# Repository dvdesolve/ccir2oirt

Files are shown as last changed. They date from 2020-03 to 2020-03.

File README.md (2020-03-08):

# ccir2oirt
This converter is intended for shifting radio frequency down so old radio receivers which works in OIRT range (mostly produced in Soviet Union) become able to receive modern CCIR range. It have 3 frequency range selectors: 88-96, 95-103 and 101-109 MHz. Input voltage is quite wide and spans from 7V to 25V (for both positive and negative versions). It's recommended to place the whole device in solid aluminum box to prevent unintended RF interference.

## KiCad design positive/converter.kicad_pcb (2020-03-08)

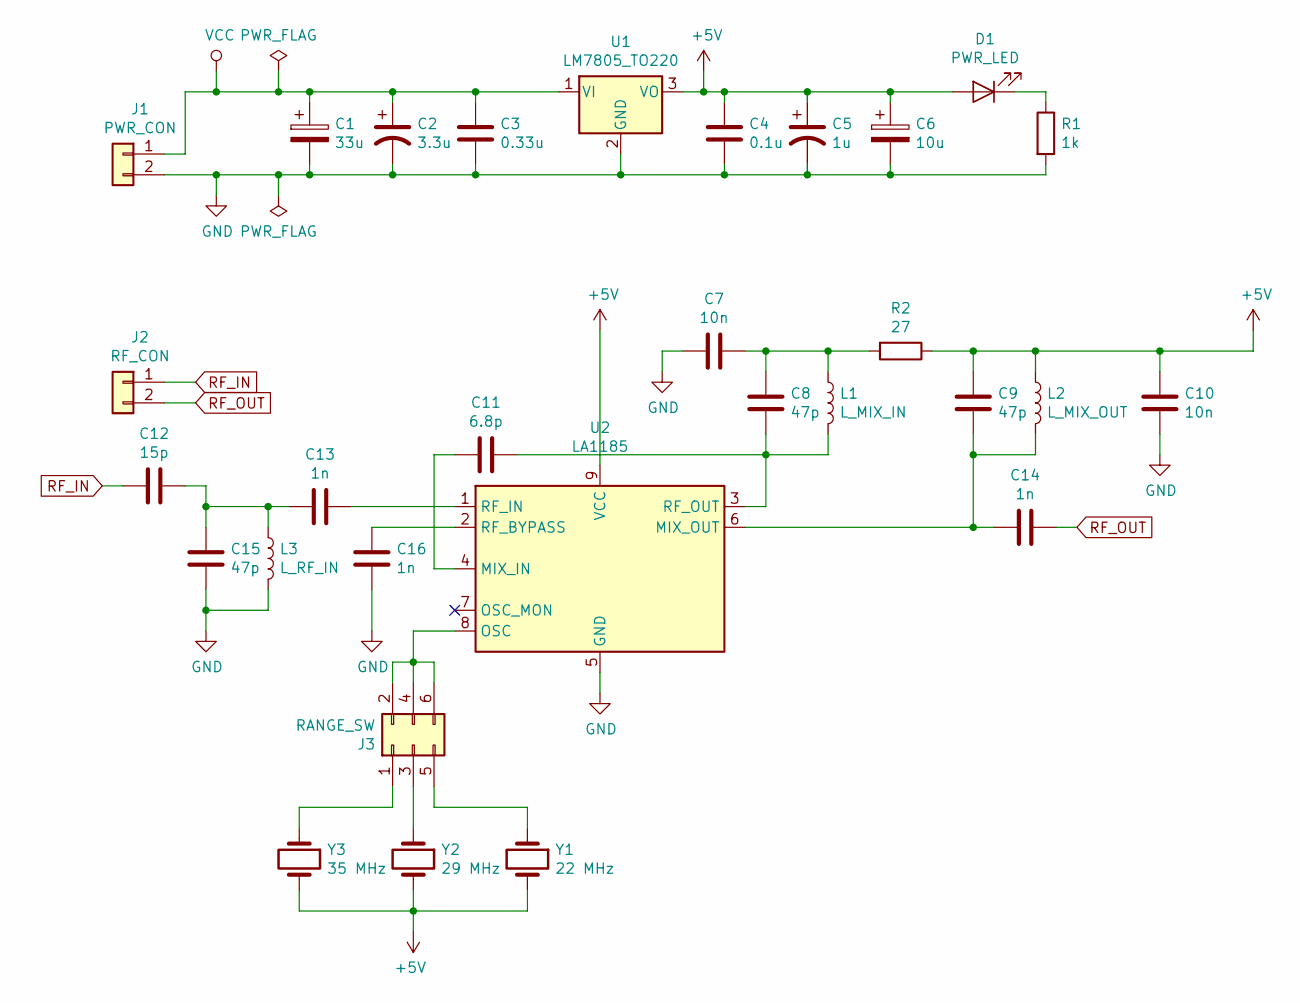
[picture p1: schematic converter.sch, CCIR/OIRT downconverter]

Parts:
C1: 33u; CP_Radial_D5.0mm_P2.00mm
C2: 3.3u; CP_EIA-3528-21_Kemet-B_Pad1.50x2.35mm_HandSolder
C3: 0.33u; C_Disc_D4.7mm_W2.5mm_P5.00mm
C4: 0.1u; C_Disc_D4.7mm_W2.5mm_P5.00mm
C5: 1u; CP_EIA-3216-18_Kemet-A_Pad1.58x1.35mm_HandSolder
C6: 10u; CP_Radial_D5.0mm_P2.00mm
C7, C10: 10n; C_Disc_D4.7mm_W2.5mm_P5.00mm
C8, C9, C15: 47p; C_Disc_D4.7mm_W2.5mm_P5.00mm
C11: 6.8p; C_Rect_L6.8mm_W4.6mm_P2.50mm
C12: 15p; C_Disc_D4.7mm_W2.5mm_P5.00mm
C13, C14, C16: 1n; C_Disc_D4.7mm_W2.5mm_P5.00mm
D1: PWR_LED; LED_D5.0mm
J1: PWR_CON; Connfly_DS1070-2MR_1x02_P2.54mm
J2: RF_CON; Connfly_DS1070-2MR_1x02_P2.54mm
J3: RANGE_SW; PinHeader_2x03_P2.54mm_Horizontal
L1: L_MIX_IN; L_Axial_4Turns_d0.8mm_D4.5mm_WP1.0mm
L2: L_MIX_OUT; L_Axial_6Turns_d0.8mm_D4.5mm_WP1.0mm
L3: L_RF_IN; L_Axial_4Turns_d0.8mm_D4.5mm_WP1.0mm
R1: 1k; R_Axial_DIN0207_L6.3mm_D2.5mm_P10.16mm_Horizontal
R2: 27; R_Axial_DIN0207_L6.3mm_D2.5mm_P10.16mm_Horizontal
U1: LM7805_TO220; TO-220-3_Vertical
U2: LA1185; SIP-9_21.54x3mm_P2.54mm
Y1: 22 MHz; Crystal_HC49-U_Vertical
Y2: 29 MHz; Crystal_HC49-U_Vertical
Y3: 35 MHz; Crystal_HC49-U_Vertical

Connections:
+5V: C4.1, C5.1, C6.1, C9.1, C10.1, D1.2 (A), L2.1, R2.1, U1.3 (VO), U2.9 (VCC), Y1.2, Y2.2, Y3.2
GND: C1.2, C2.2, C3.2, C4.2, C5.2, C6.2, C7.2, C10.2, C15.2, C16.2, J1.2, L3.2, R1.2, U1.2 (GND), U2.5 (GND); also elsewhere on the board
unnamed: C7.1, C8.1, L1.1, R2.2
unnamed: C8.2, C11.1, L1.2, U2.3 (RF_OUT)
unnamed: C11.2, U2.4 (MIX_IN)
unnamed: C12.1, C13.2, C15.1, L3.1
unnamed: C13.1, U2.1 (RF_IN)
unnamed: C9.2, C14.2, L2.2, U2.6 (MIX_OUT)
unnamed: C16.1, U2.2 (RF_BYPASS)
unnamed: D1.1 (K), R1.1
unnamed: J3.1, Y3.1
unnamed: J3.2, J3.4, J3.6, U2.8 (OSC)
unnamed: J3.3, Y2.1
unnamed: J3.5, Y1.1
RF_IN: C12.2, J2.1
RF_OUT: C14.1, J2.2
VCC: C1.1, C2.1, C3.1, J1.1, U1.1 (VI)

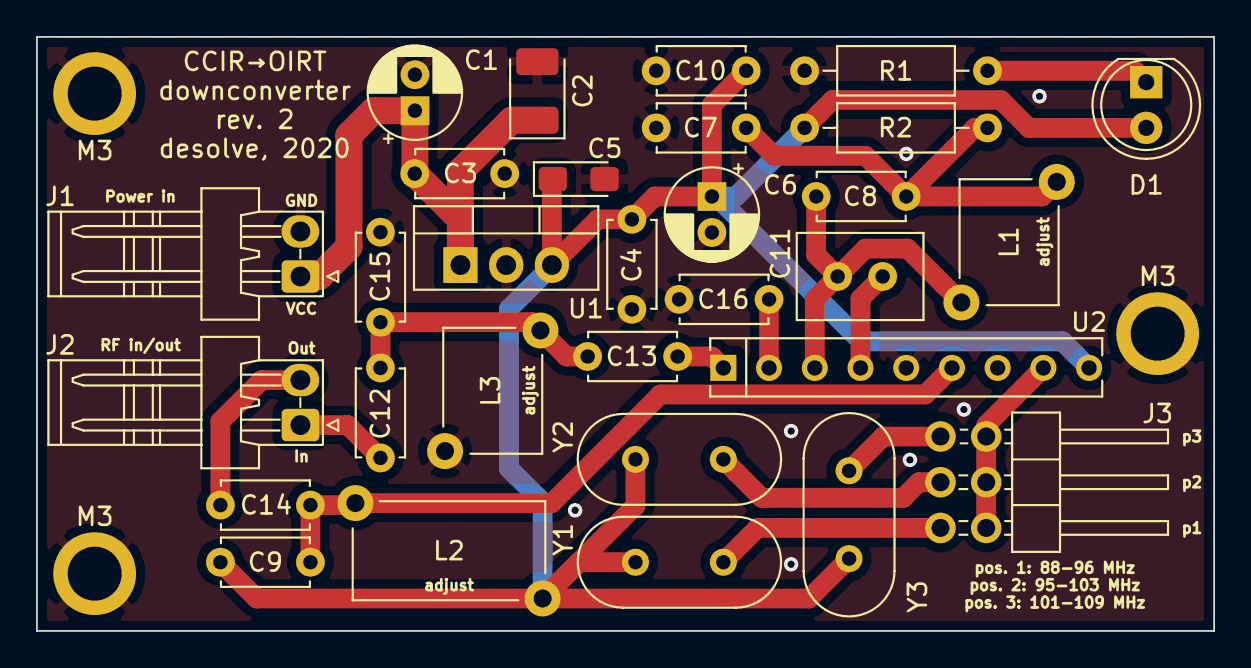
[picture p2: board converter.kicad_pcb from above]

Board: 2 copper layers, 65.4 x 33.0 mm, 33 parts (0 on the bottom side), 17 nets.

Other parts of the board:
M3, M3#2, M3#3: M3; Pin_D1.0mm_L10.0mm

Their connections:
GND: M3.1, M3#2.1, M3#3.1; also elsewhere on the board
